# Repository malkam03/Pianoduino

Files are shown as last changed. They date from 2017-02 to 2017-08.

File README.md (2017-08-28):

# Pianoduino
A 61 key MIDI keyboard project with Arduino and some parts of a broken Yamaha PSR-E303. With control knobs, buttons, LCD and resistive panel. 
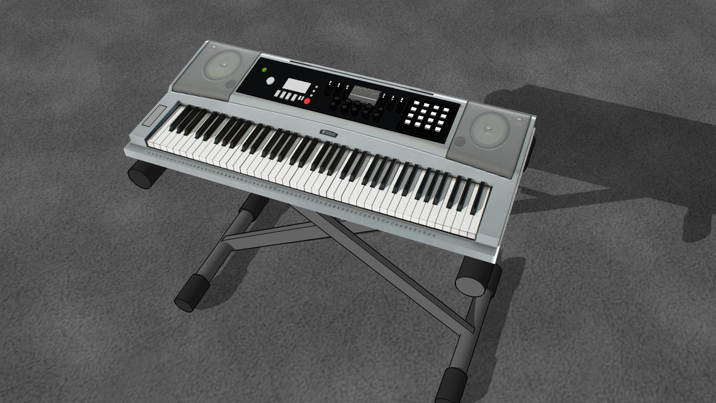
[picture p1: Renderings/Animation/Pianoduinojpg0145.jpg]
Image of Pianoduino

## Getting Started
Since this is a hardware and software project, these instructions will get you a copy of the project up and running on your device for development and testing purposes.  

### Prerequisites

**Arduino Circuit**
First you need to build the [circuit](PCB/Pianoduino/Mainboard.brd) if you have a Yamaha PSR-E303, or you can modify it to fit your keys circuit.
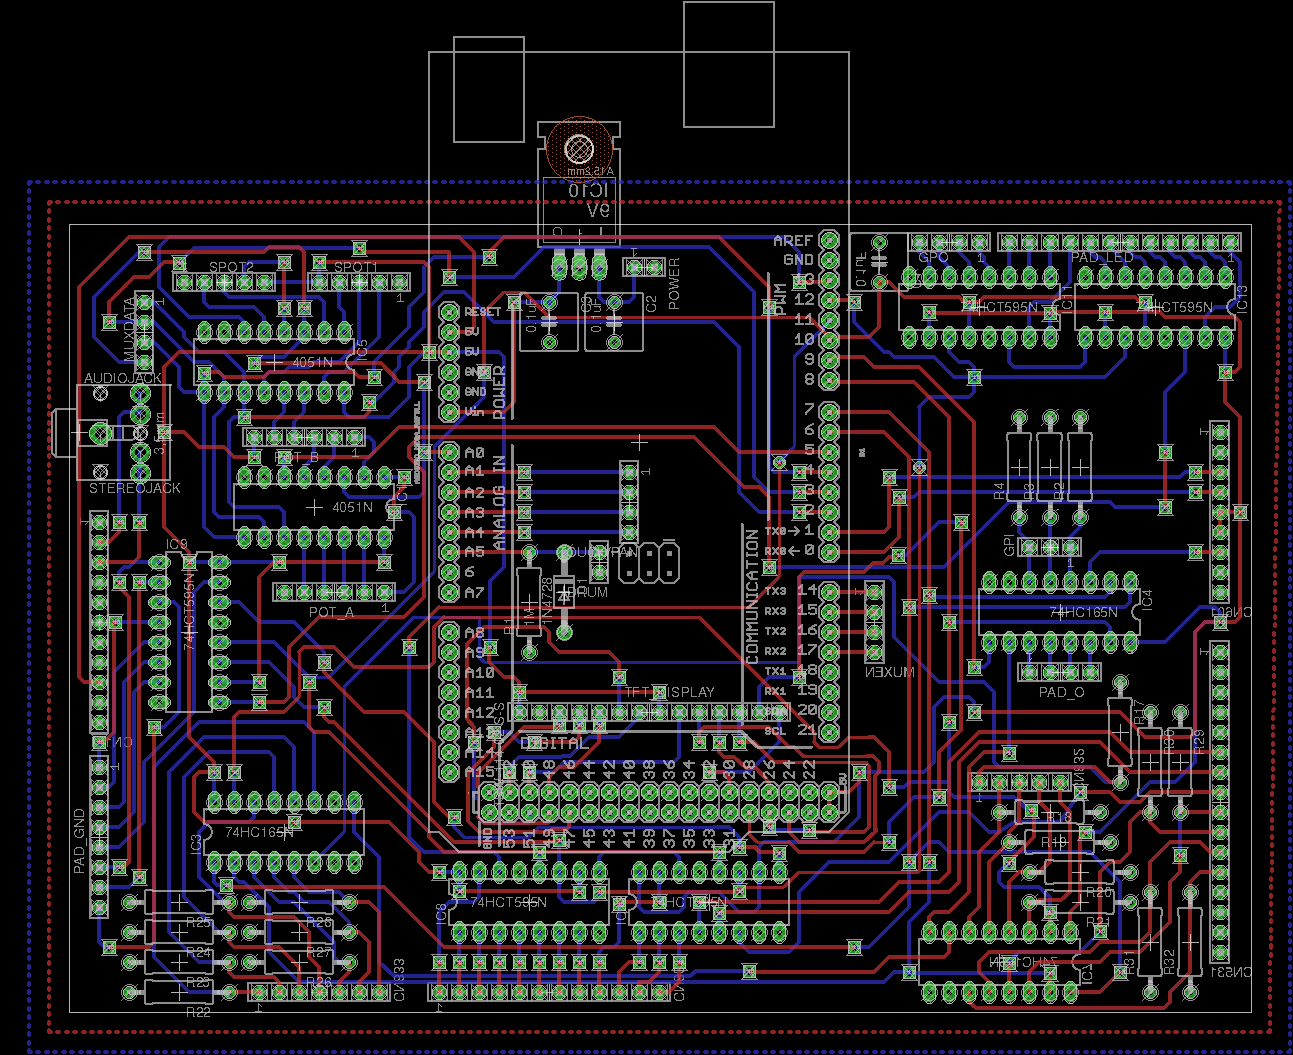
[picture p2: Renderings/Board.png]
PCB


**Arduino IDE** to edit and upload your code.
You can find the instructions of installation on the Arduino's [page](https://www.arduino.cc/en/Main/Software) depending on your operative system.

**Autodesk Eagle** to edit the circuit.
You can find the instructions of installation on the autodesk's [page](https://www.autodesk.com/products/eagle/free-download) depending on your operative system.

## Deployment

Just upload your code to the arduino + circuit and play :musical_keyboard:.

## Author
* **Malcolm Davis** - *Initial work* - [Pianoduino](https://github.com/malkam03/Pianoduino)

See also the list of [contributors](https://github.com/malkam03/Pianoduino/contributors.md) who participated in this project.

## License

This project is licensed under the MIT License - see the [LICENSE.md](LICENSE.md) file for details.

## Acknowledgments

* [Brian Benchoff](https://hackaday.com/2012/11/28/turning-toy-pianos-into-midi-keyboards/)
* [dylanstout](http://www.instructables.com/id/Arduino-MIDI-Controller/)
* [cgmalantonio](http://www.instructables.com/id/Touch-Screen-Overlay-with-Arduino/)

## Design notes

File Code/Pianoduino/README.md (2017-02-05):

# Pianoduino
A 61 key MIDI keyboard project with Arduino. With control knobs, buttons, LCD and resistive panel.

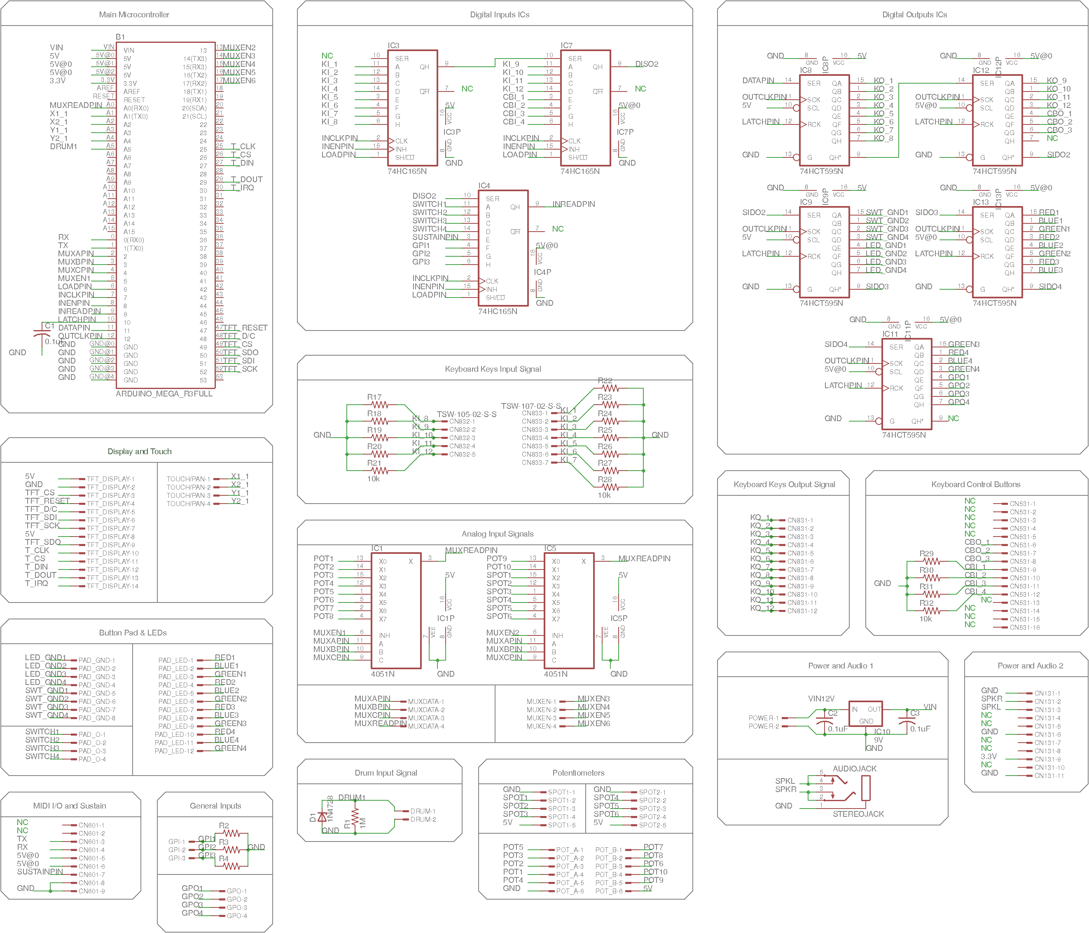
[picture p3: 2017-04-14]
Renderings/Schematic.png

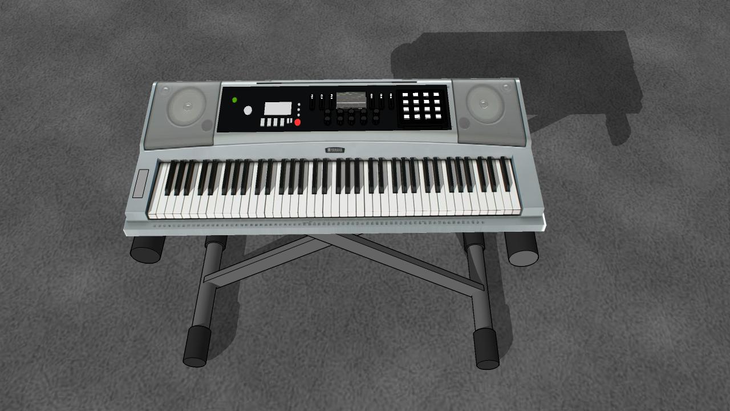
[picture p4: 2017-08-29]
Renderings/Animation/Pianoduinojpg0058.jpg

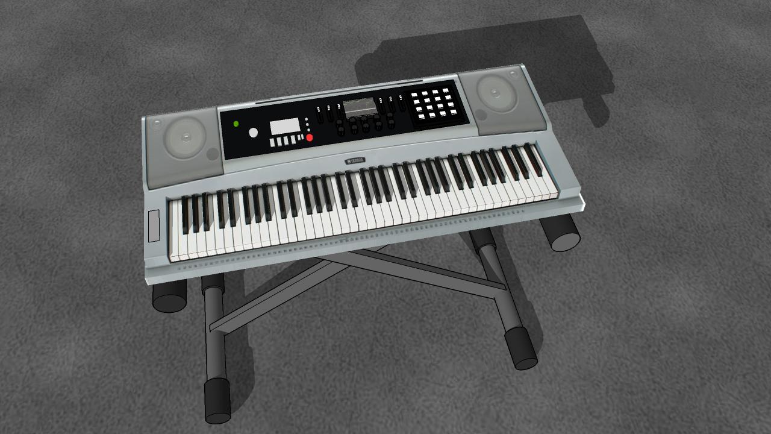
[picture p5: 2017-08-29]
Renderings/Animation/Pianoduinojpg0084.jpg

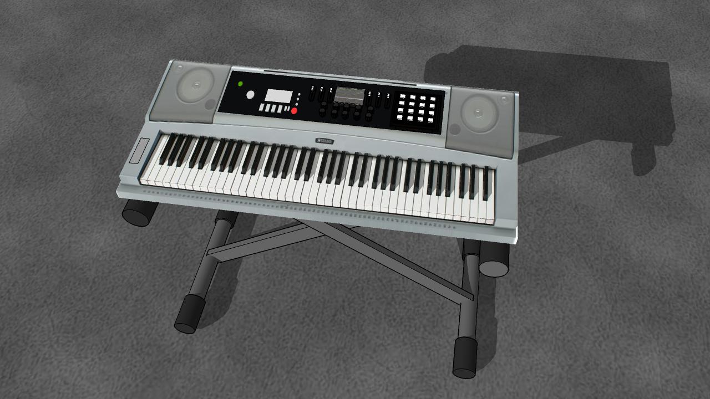
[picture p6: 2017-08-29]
Renderings/Animation/Pianoduinojpg0034.jpg

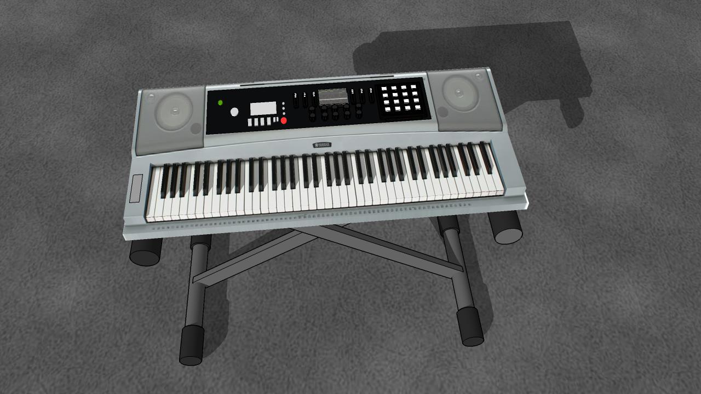
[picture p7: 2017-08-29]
Renderings/Animation/Pianoduinojpg0069.jpg

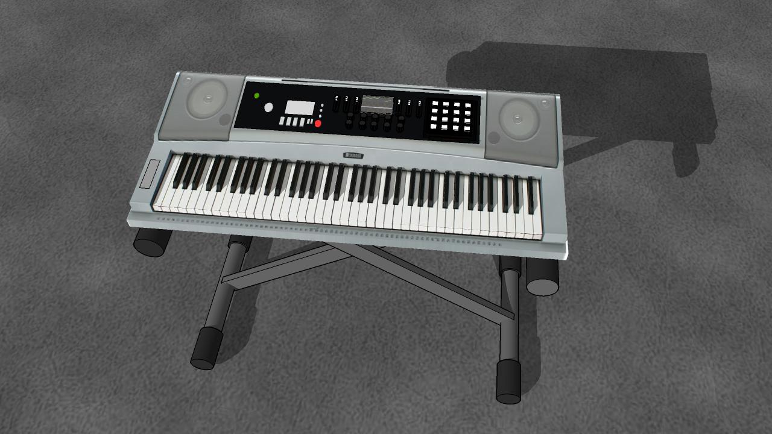
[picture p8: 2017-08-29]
Renderings/Animation/Pianoduinojpg0042.jpg

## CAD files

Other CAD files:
Datasheets/TJCTM32024_SPI/51_Code-keil/»ù±¾Ë¢ÆÁ²âÊÔ/main.OBJ
Datasheets/TJCTM32024_SPI/51_Code-keil/×ÛºÏ²âÊÔ(ÒªÇó´óÓÚ16K ROMµÄµ¥Æ¬»ú)/×ÛºÏ²âÊÔ(ÒªÇó´óÓÚ16K ROMµÄµ¥Æ¬»ú)/main.OBJ
Datasheets/TJCTM32024_SPI/51_Code-keil/»ù±¾Ë¢ÆÁ²âÊÔ/sys.obj
Datasheets/TJCTM32024_SPI/51_Code-keil/×ÛºÏ²âÊÔ(ÒªÇó´óÓÚ16K ROMµÄµ¥Æ¬»ú)/×ÛºÏ²âÊÔ(ÒªÇó´óÓÚ16K ROMµÄµ¥Æ¬»ú)/touch.obj
Datasheets/TJCTM32024_SPI/51_Code-keil/»ù±¾Ë¢ÆÁ²âÊÔ/LCD.obj
Datasheets/TJCTM32024_SPI/51_Code-keil/×ÛºÏ²âÊÔ(ÒªÇó´óÓÚ16K ROMµÄµ¥Æ¬»ú)/×ÛºÏ²âÊÔ(ÒªÇó´óÓÚ16K ROMµÄµ¥Æ¬»ú)/STARTUP.OBJ
Datasheets/TJCTM32024_SPI/51_Code-keil/»ù±¾Ë¢ÆÁ²âÊÔ/font.obj
Datasheets/TJCTM32024_SPI/51_Code-keil/×ÛºÏ²âÊÔ(ÒªÇó´óÓÚ16K ROMµÄµ¥Æ¬»ú)/×ÛºÏ²âÊÔ(ÒªÇó´óÓÚ16K ROMµÄµ¥Æ¬»ú)/sys.obj
Datasheets/TJCTM32024_SPI/51_Code-keil/»ù±¾Ë¢ÆÁ²âÊÔ/touch.obj
Datasheets/TJCTM32024_SPI/51_Code-keil/×ÛºÏ²âÊÔ(ÒªÇó´óÓÚ16K ROMµÄµ¥Æ¬»ú)/×ÛºÏ²âÊÔ(ÒªÇó´óÓÚ16K ROMµÄµ¥Æ¬»ú)/font.obj
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

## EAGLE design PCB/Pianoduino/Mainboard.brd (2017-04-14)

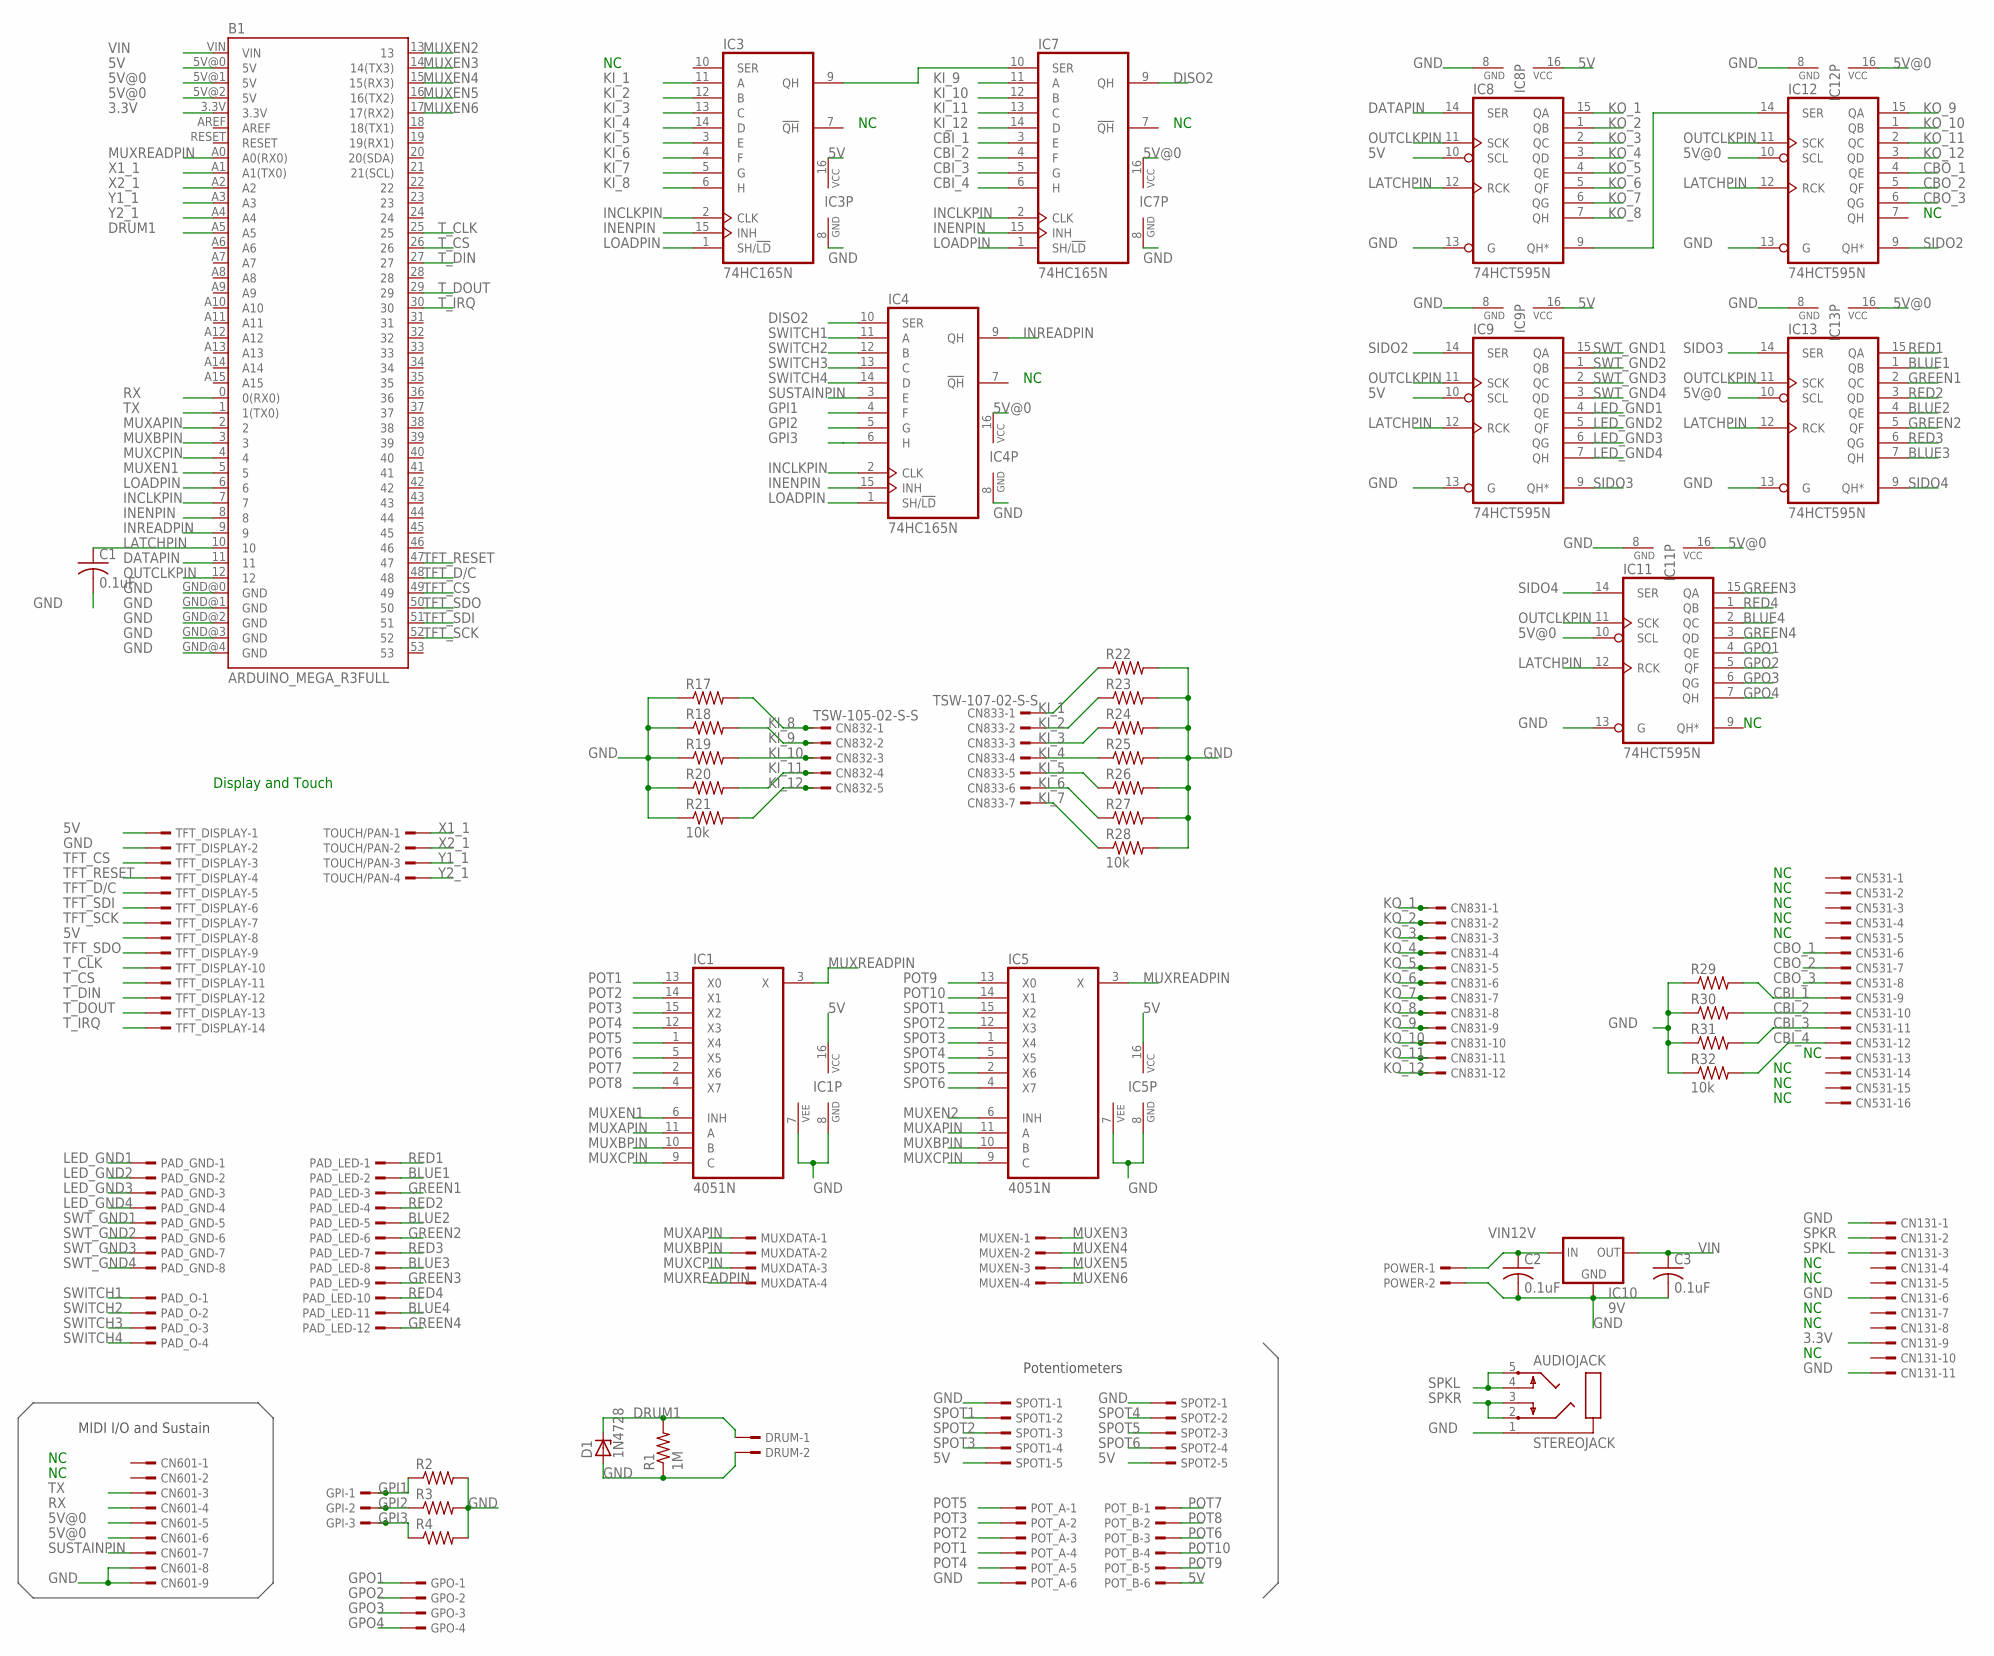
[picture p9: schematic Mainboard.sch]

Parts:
AUDIOJACK: STEREOJACK; STX3100
B1: ARDUINO_MEGA_R3FULL; ARDUINO_MEGA
C1, C2, C3: 0.1uF; C050-075X075
CN131: TSW-111-02-S-S
CN531: TSW-116-02-S-S
CN601: TSW-109-02-S-S
CN831: TSW-112-02-S-S
CN832: TSW-105-02-S-S
CN833: TSW-107-02-S-S
D1: 1N4728; DO41Z10
DRUM: TSW-102-02-S-S
GPI: TSW-103-02-S-S
GPO: TSW-104-02-S-S
IC1, IC5: 4051N; DIL16
IC3, IC4, IC7: 74HC165N; DIL16
IC8, IC9, IC11, IC12, IC13: 74HCT595N; DIL16
IC10: 9V; 78XXL
MUXDATA: TSW-104-02-S-S
MUXEN: TSW-104-02-S-S
PAD_GND: TSW-108-02-S-S
PAD_LED: TSW-112-02-S-S
PAD_O: TSW-104-02-S-S
POT_A: TSW-106-02-S-S
POT_B: TSW-106-02-S-S
POWER: TSW-102-02-S-S
R1: 1M; 0309/12
R2, R3, R4, R17, R18, R19, R20, R21, R22, R23, R24, R25, R26, R27, R28, R29, R30, R31, R32: 10k; 0309/12
SPOT1, SPOT2: TSW-105-02-S-S
TFT_DISPLAY: TSW-114-02-S-S
TOUCH/PAN: TSW-104-02-S-S

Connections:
3.3V: B1.3.3V, CN131.9
5V: B1.5V@0 (5V), IC1.16 (VCC), IC3.16 (VCC), IC5.16 (VCC), IC8.10 (SCL), IC8.16 (VCC), IC9.10 (SCL), IC9.16 (VCC), POT_B.6, SPOT1.5, SPOT2.5, TFT_DISPLAY.1, TFT_DISPLAY.8
5V@0: B1.5V@1 (5V), B1.5V@2 (5V), CN601.5, CN601.6, IC4.16 (VCC), IC7.16 (VCC), IC11.10 (SCL), IC11.16 (VCC), IC12.10 (SCL), IC12.16 (VCC), IC13.10 (SCL), IC13.16 (VCC)
BLUE1: IC13.1 (QB), PAD_LED.2
BLUE2: IC13.4 (QE), PAD_LED.5
BLUE3: IC13.7 (QH), PAD_LED.8
BLUE4: IC11.2 (QC), PAD_LED.11
CBI_1: CN531.9, IC7.3 (E), R29.2
CBI_2: CN531.10, IC7.4 (F), R30.2
CBI_3: CN531.11, IC7.5 (G), R31.2
CBI_4: CN531.12, IC7.6 (H), R32.2
CBO_1: CN531.6, IC12.4 (QE)
CBO_2: CN531.7, IC12.5 (QF)
CBO_3: CN531.8, IC12.6 (QG)
DATAPIN: B1.11, IC8.14 (SER)
DISO1: IC3.9 (QH), IC7.10 (SER)
DISO2: IC4.10 (SER), IC7.9 (QH)
DRUM1: B1.A5, D1.C, DRUM.1, R1.2
GND: AUDIOJACK.1, B1.GND@0 (GND), B1.GND@1 (GND), B1.GND@2 (GND), B1.GND@3 (GND), B1.GND@4 (GND), C1.2, C2.2, C3.2, CN131.1, CN131.6, CN131.11, CN601.8, CN601.9, D1.A, DRUM.2, IC1.7 (VEE), IC1.8 (GND), IC3.8 (GND), IC4.8 (GND), IC5.7 (VEE), IC5.8 (GND), IC7.8 (GND), IC8.8 (GND), IC8.13 (G), IC9.8 (GND), IC9.13 (G), IC10.GND, IC11.8 (GND), IC11.13 (G), IC12.8 (GND), IC12.13 (G), IC13.8 (GND), IC13.13 (G), POT_A.6, POWER.2, R1.1, R2.2, R3.2, R4.2, R17.1, R18.1, R19.1, R20.1, R21.1, R22.2, R23.2, R24.2, R25.2, R26.2, R27.2, R28.2, R29.1, R30.1, R31.1, R32.1, SPOT1.1, SPOT2.1, TFT_DISPLAY.2
GPI1: GPI.1, IC4.4 (F), R2.1
GPI2: GPI.2, IC4.5 (G), R3.1
GPI3: GPI.3, IC4.6 (H), R4.1
GPO1: GPO.1, IC11.4 (QE)
GPO2: GPO.2, IC11.5 (QF)
GPO3: GPO.3, IC11.6 (QG)
GPO4: GPO.4, IC11.7 (QH)
GREEN1: IC13.2 (QC), PAD_LED.3
GREEN2: IC13.5 (QF), PAD_LED.6
GREEN3: IC11.15 (QA), PAD_LED.9
GREEN4: IC11.3 (QD), PAD_LED.12
INCLKPIN: B1.7, IC3.2 (CLK), IC4.2 (CLK), IC7.2 (CLK)
INENPIN: B1.8, IC3.15 (INH), IC4.15 (INH), IC7.15 (INH)
INREADPIN: B1.9, IC4.9 (QH)
KI_1: CN833.1, IC3.11 (A), R22.1
KI_2: CN833.2, IC3.12 (B), R23.1
KI_3: CN833.3, IC3.13 (C), R24.1
KI_4: CN833.4, IC3.14 (D), R25.1
KI_5: CN833.5, IC3.3 (E), R26.1
KI_6: CN833.6, IC3.4 (F), R27.1
KI_7: CN833.7, IC3.5 (G), R28.1
KI_8: CN832.1, IC3.6 (H), R17.2
KI_9: CN832.2, IC7.11 (A), R18.2
KI_10: CN832.3, IC7.12 (B), R19.2
KI_11: CN832.4, IC7.13 (C), R20.2
KI_12: CN832.5, IC7.14 (D), R21.2
KO_1: CN831.1, IC8.15 (QA)
KO_2: CN831.2, IC8.1 (QB)
KO_3: CN831.3, IC8.2 (QC)
KO_4: CN831.4, IC8.3 (QD)
KO_5: CN831.5, IC8.4 (QE)
KO_6: CN831.6, IC8.5 (QF)
KO_7: CN831.7, IC8.6 (QG)
KO_8: CN831.8, IC8.7 (QH)
KO_9: CN831.9, IC12.15 (QA)
KO_10: CN831.10, IC12.1 (QB)
KO_11: CN831.11, IC12.2 (QC)
KO_12: CN831.12, IC12.3 (QD)
LATCHPIN: B1.10, C1.1, IC8.12 (RCK), IC9.12 (RCK), IC11.12 (RCK), IC12.12 (RCK), IC13.12 (RCK)
LED_GND1: IC9.4 (QE), PAD_GND.1
LED_GND2: IC9.5 (QF), PAD_GND.2
LED_GND3: IC9.6 (QG), PAD_GND.3
LED_GND4: IC9.7 (QH), PAD_GND.4
LOADPIN: B1.6, IC3.1 (SH/!LD), IC4.1 (SH/!LD), IC7.1 (SH/!LD)
MUXAPIN: B1.2, IC1.11 (A), IC5.11 (A), MUXDATA.1
MUXBPIN: B1.3, IC1.10 (B), IC5.10 (B), MUXDATA.2
MUXCPIN: B1.4, IC1.9 (C), IC5.9 (C), MUXDATA.3
MUXEN1: B1.5, IC1.6 (INH)
MUXEN2: B1.13, IC5.6 (INH)
MUXEN3: B1.14 (14(TX3)), MUXEN.1
MUXEN4: B1.15 (15(RX3)), MUXEN.2
MUXEN5: B1.16 (16(TX2)), MUXEN.3
MUXEN6: B1.17 (17(RX2)), MUXEN.4
MUXREADPIN: B1.A0 (A0(RX0)), IC1.3 (X), IC5.3 (X), MUXDATA.4
unnamed: IC8.9 (QH*), IC12.14 (SER)
OUTCLKPIN: B1.12, IC8.11 (SCK), IC9.11 (SCK), IC11.11 (SCK), IC12.11 (SCK), IC13.11 (SCK)
POT1: IC1.13 (X0), POT_A.4
POT2: IC1.14 (X1), POT_A.3
POT3: IC1.15 (X2), POT_A.2
POT4: IC1.12 (X3), POT_A.5
POT5: IC1.1 (X4), POT_A.1
POT6: IC1.5 (X5), POT_B.3
POT7: IC1.2 (X6), POT_B.1
POT8: IC1.4 (X7), POT_B.2
POT9: IC5.13 (X0), POT_B.5
POT10: IC5.14 (X1), POT_B.4
RED1: IC13.15 (QA), PAD_LED.1
RED2: IC13.3 (QD), PAD_LED.4
RED3: IC13.6 (QG), PAD_LED.7
RED4: IC11.1 (QB), PAD_LED.10
RX: B1.0 (0(RX0)), CN601.4
SIDO2: IC9.14 (SER), IC12.9 (QH*)
SIDO3: IC9.9 (QH*), IC13.14 (SER)
SIDO4: IC11.14 (SER), IC13.9 (QH*)
SPKL: AUDIOJACK.4, AUDIOJACK.5, CN131.3
SPKR: AUDIOJACK.2, AUDIOJACK.3, CN131.2
SPOT1: IC5.15 (X2), SPOT1.2
SPOT2: IC5.12 (X3), SPOT1.3
SPOT3: IC5.1 (X4), SPOT1.4
SPOT4: IC5.5 (X5), SPOT2.2
SPOT5: IC5.2 (X6), SPOT2.3
SPOT6: IC5.4 (X7), SPOT2.4
SUSTAINPIN: CN601.7, IC4.3 (E)
SWITCH1: IC4.11 (A), PAD_O.1
SWITCH2: IC4.12 (B), PAD_O.2
SWITCH3: IC4.13 (C), PAD_O.3
SWITCH4: IC4.14 (D), PAD_O.4
SWT_GND1: IC9.15 (QA), PAD_GND.5
SWT_GND2: IC9.1 (QB), PAD_GND.6
SWT_GND3: IC9.2 (QC), PAD_GND.7
SWT_GND4: IC9.3 (QD), PAD_GND.8
TFT_CS: B1.49, TFT_DISPLAY.3
TFT_D/C: B1.48, TFT_DISPLAY.5
TFT_RESET: B1.47, TFT_DISPLAY.4
TFT_SCK: B1.52, TFT_DISPLAY.7
TFT_SDI: B1.51, TFT_DISPLAY.6
TFT_SDO: B1.50, TFT_DISPLAY.9
TX: B1.1 (1(TX0)), CN601.3
T_CLK: B1.25, TFT_DISPLAY.10
T_CS: B1.26, TFT_DISPLAY.11
T_DIN: B1.27, TFT_DISPLAY.12
T_DOUT: B1.29, TFT_DISPLAY.13
T_IRQ: B1.30, TFT_DISPLAY.14
VIN: B1.VIN, C3.1, IC10.OUT
VIN12V: C2.1, IC10.IN, POWER.1
X1_1: B1.A1 (A1(TX0)), TOUCH/PAN.1
X2_1: B1.A2, TOUCH/PAN.2
Y1_1: B1.A3, TOUCH/PAN.3
Y2_1: B1.A4, TOUCH/PAN.4

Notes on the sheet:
MIDI I/O and Sustain
Potentiometers
Display and Touch

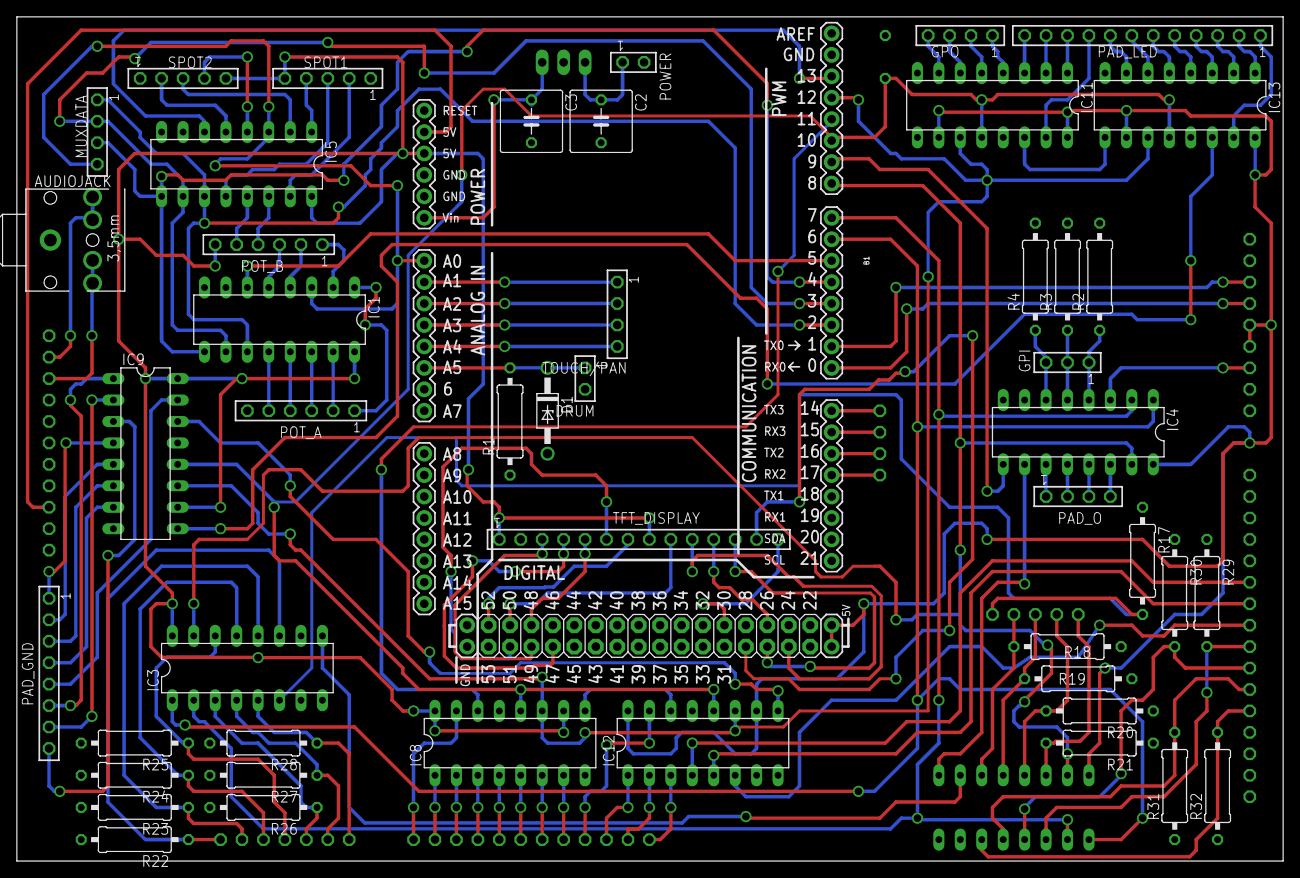
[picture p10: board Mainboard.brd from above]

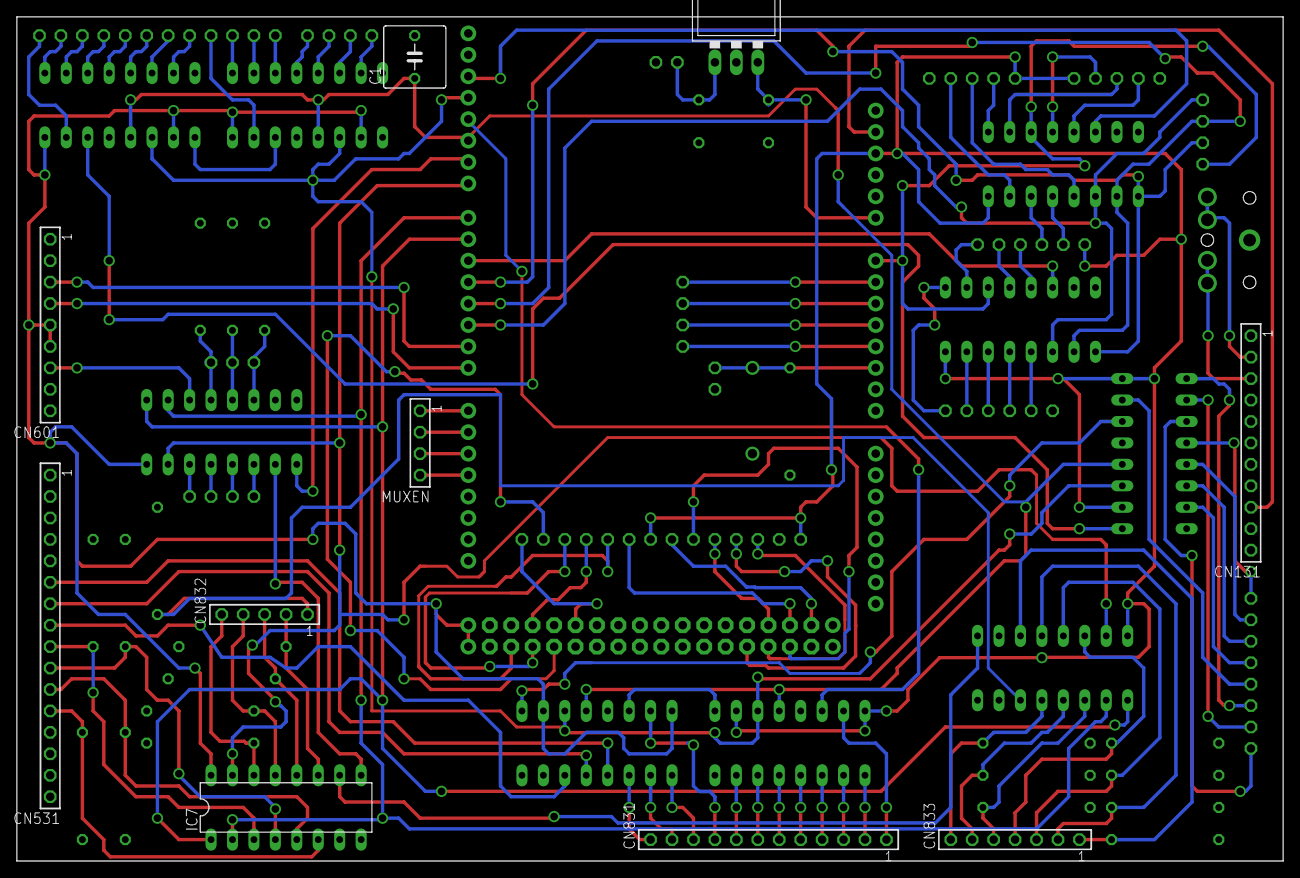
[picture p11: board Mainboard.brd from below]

Board: 2 copper layers, 150.0 x 100.0 mm, 58 parts (10 on the bottom side), 128 nets.

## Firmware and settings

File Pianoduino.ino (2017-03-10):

/**
 * <h1>Pianoduino</h1>
 * 61 key MIDI Keyboard with Arduino Uno Code, 24 shiftout outputs, 24 shiftin inputs
 * 1 resistive touchscreen and 16 analog I/O.
 * @author Malcolm Davis
 * @version 0.1
 * @since 2017-02-03
 */

//*********************Arduino Pins*************************//
static const byte muxAPin = 2;
static const byte muxBPin = 3;
static const byte muxCPin = 4;
static const byte muxReadPin = A0;
static const byte inClkPin = 7; //Shift in clock
static const byte loadPin = 6; //Shift in or load input. When high data, shifted. When Low data is loaded from parallel inputs.
static const byte inEnPin = 8; //Active low
static const byte inReadPin = 9;
static const byte dataPin = 11;
static const byte outClkPin = 12;
static const byte latchPin = 10;
//If a Analog mux is added, just connect the control pins in parallel and add the En pin to the list.
static const byte muxEn [] = {
  5};
//**********************************************************//

//**************************Constants*********************//
byte mask[] = { 
  B00000001, B00000010, B00000100, B00001000, B00010000, B00100000, B01000000, B10000000 };//To read the columns values
static const byte  keyMidiCons[144] = {
  0, 0, 0, 0, 0, 0, 0, 0, 0, 0, 0, 0,
  0, 0, 0, 0, 0, 0, 0, 0, 0, 0, 0, 0,
  0, 0, 0, 0, 0, 0, 0, 0, 0, 0, 0, 0,
  B00101000, B00101000, B00101001, B00101001, B00101010, B00101010, B00101011, B00101011, B00101100, B00101100, B00100111, B00100111,
  B00101110, B00101110, B00101111, B00101111, B00110000, B00110000, B00101011, B00101011, B00101100, B00101100, B00101101, B00101101,
  B00111010, B00111010, B00111011, B00111011, 0, 0, B00110111, B00110111, B00111000, B00111000, B00111001, B00111001,
  B00110100, B00110100, B00110101, B00110101, B00110110, B00110110, B00110001, B00110001, B00110010, B00110010, B00110011, B00110011,
  B01010010, B01010010, B01010011, B01010011, B01010100, B01010100, B01001111, B01001111, B01010000, B01010000, B01010001, B01010001,
  B01001100, B01001100, B01001101, B01001101, B01001110, B01001110, B01001001, B01001001, B01001010, B01001010, B01001011, B01001011,
  B01000110, B01000110, B01000111, B01000111, B01001000, B01001000, B01000011, B01000011, B01000100, B01000100, B01000101, B01000101,
  B01000000, B01000000, B01000001, B01000001, B01000010, B01000010, B00111101, B00111101, B00111110, B00111110, B00111111, B00111111,
  0, 0, 0, 0, B00111100, B00111100, 0, 0, 0, 0, 0, 0
};
static const byte drumNotes []= {
  B00100110
}; //Drums note, snaredrum,...
static const byte blank = B00000000;//To send blank to the register.
static const byte noteON = B10010000;
static const byte noteOFF = B10000000;
static const byte control = B10110000;
static const byte pitchBend = B11100000;
static const byte  padMidi = B00000000; //Pad first note.
static const byte  buttonMidi = B00010000; //Controll general first code.
static const byte analogMidi =B00110000; //Controll general first code.
// MIDI codes taken from http://nickfever.com/music/midi-cc-list
static const byte MIDI_CC_MODULATION = B00000001;
static const byte MIDI_CC_VOLUME = B00000111;
static const byte MIDI_CC_BALANCE = B00001000;
static const byte MIDI_CC_SUSTAIN = B00101000;
static const byte MIDI_CC_NOTES_OFF = B01111011;



//Shift in movements(3 shift registers and 8 pins per shift register)
//The sum of all the rows have to be smaller or equal to the shift in registers.
static const byte shiftIns=24; 
//*******************Configuration constants**********************//
//Don't change this values unless you change the hardware.
static const byte keyColumns = 12;
static const byte keyRows = 12; //
static const byte buttonColumns = 3;
static const byte buttonRows = 4; 
static const byte padColumns = 4;
static const byte padRows = 4;
//This values can be changed.
static const short sensitivity = 1000;
static const byte keyboardChannel = 1;
static const byte buttonPadChannel = 2;
static const byte controlChannel = 3;
static const byte drumsChannel = 4;
static const byte drumsThreshold [] = { 
40 
};//Drums threshold, snaredrum,...
static const byte analogThreshold = 1;
//#define debug //Uncomment to debug
//***************************************************************//

//*******************************Variables**********************//
static bool sValue[] = {
  0, 0, 0}; // S0, S1, S2 values
long noteTime [sizeof(keyMidiCons) / sizeof(byte) / 2]; //Time that the note have been pressed.
bool keyState[sizeof(keyMidiCons) / sizeof(byte)]; //State of the key.
bool buttonState[buttonColumns*buttonRows]; //State of the buttons.
bool padState[padRows*padColumns]; //State of the pad buttons.
bool rowsRead [keyRows+buttonRows]; // Rows shift in values.
byte trans = 0; //Level to transpose the octaves.
static byte  keyMidi[sizeof(keyMidiCons) / sizeof(byte)]; 
byte analogValue[(sizeof(muxEn) / sizeof(byte)) * 8]; 
//**************************************************************//


/**
 * Method to setup the pins and stuffs of the pianoduino.
 * @param none
 * @return void
 */
void setup() {
  byte i;
  Serial.begin(115200);
#ifdef debug 
  Serial.println("Setup Start");
#endif
  pinMode(muxAPin, OUTPUT);
  pinMode(muxBPin, OUTPUT);
  pinMode(muxCPin, OUTPUT);
  pinMode(inClkPin, OUTPUT);
  pinMode(loadPin, OUTPUT);
  pinMode(inEnPin, OUTPUT);
  pinMode(inReadPin, INPUT);
  pinMode(dataPin, OUTPUT);
  pinMode(latchPin, OUTPUT);
  pinMode(outClkPin, OUTPUT);
  //Set the enabler pins to outputs.
  for (i = 0; i < sizeof(muxEn) / sizeof(int); i++) {
    pinMode(muxEn[i], OUTPUT);
  }
  //Set the note times to 0
  for (i = 0; i < sizeof(noteTime) / sizeof(long); i++) {
    noteTime[i] = 0;
  }
  //Set all the notes as off
  for (i = 0; i < sizeof(keyState) / sizeof(bool); i++) {
    keyState[i] = 0;
  }
  //Set all the row read values to false
  for (i = 0; i < keyRows+buttonRows; i++){
    rowsRead[i] = false;
  }
  //Set all the buttons of the pad to off.
  for (i = 0; i < padColumns*padRows; i++){
    padState[i] = 0;
  }
  //Set all the buttons of the pad to off.
  for (i = 0; i < buttonRows*buttonColumns; i++){
    buttonState[i] = 0;
  }

  readAnalog(); //Read the initial value of the knobs
  transpose(trans); //Set the octave to the initial value.
  digitalWrite(loadPin, HIGH); //On HIGH is read ready
  delay(1000); //Waits a second.
#ifdef debug 
  Serial.println("Setup Ready");
#endif
}

/**
 * Method to select a pin of a mux
 * @param pPin: the mux pin that you want to write or read.
 * @param pMuxEn: the pin of the mux that you want to read from.
 * @return void
 */
void muxToPin(byte pPin, byte pMuxEn) {
  sValue[0] = bitRead(pPin, 0);
  sValue[1] = bitRead(pPin, 1);
  sValue[2] = bitRead(pPin, 2);
  for (byte i = 0; i < sizeof(muxEn) / sizeof(byte); i++) {
    if (pMuxEn != i) {
      digitalWrite(muxEn[i], HIGH);
    }
  }
  digitalWrite(pMuxEn, LOW);
  digitalWrite(muxAPin, sValue[0]);
  digitalWrite(muxBPin, sValue[1]);
  digitalWrite(muxCPin, sValue[2]);
}

/**
 * Method to shift the registers to a matrix column
 * @param pColumn the column you wish to shift to.
 * @return void
 */
void shiftToColumn(byte pColumn) {
#ifdef debug 
  Serial.print("Shifting to column: ");
  Serial.println(pColumn);
  delay(10);
#endif
  digitalWrite(latchPin, LOW);
  if (pColumn < 8) {
    shiftOut(dataPin, outClkPin, MSBFIRST, mask[pColumn]);
    shiftOut(dataPin, outClkPin, MSBFIRST, blank);
    shiftOut(dataPin, outClkPin, MSBFIRST, mask[pColumn]);
  } 
  else {
    shiftOut(dataPin, outClkPin, MSBFIRST, mask[pColumn % 8]);
    shiftOut(dataPin, outClkPin, MSBFIRST, mask[pColumn % 8]);
    shiftOut(dataPin, outClkPin, MSBFIRST, blank);
  }
  digitalWrite(latchPin, HIGH);
#ifdef debug 
  Serial.println("Shift done.");
#endif
  delayMicroseconds(5);
}

/**
 * Method to transpose the notes
 * @param pDir direction to transpose
 */
void transpose(byte pDir) {
  if (-3 < trans + pDir ) {
    if (trans + pDir < 5) {
      trans = trans + pDir;
    } 
    else {
      trans = 4;
    }
  } 
  else {
    trans = -2;
  }
  for (byte i = 0; i <  sizeof(keyMidi) / sizeof(byte); i++) {
    keyMidi[i] = keyMidiCons[i] + trans * 12;
  }
}

/**
 * Method to read all the values of the knobs and other analog components. (Like the snaredrum.
 * Updates the analogValue array.
 */
void readAnalog() {
#ifdef debug 
  Serial.println("readAnalog start");
#endif
  byte tmp = 0;
  for (byte i = 0; i < sizeof(muxEn) / sizeof(byte); i++) {
    for (byte y = 0; y < 8; y++) {
      muxToPin(y, muxEn[i]);
      tmp = map(analogRead(muxReadPin), 0, 1023, 0, 127);
      if (i * 8 + y < 15) {
        //If the value is greater or smaller than the actual value plus or minus the threshold send the change value.
        if (tmp > analogValue[i * 8 + y] + analogThreshold || tmp < analogValue[i * 8 + y] - analogThreshold  ) {

          analogValue[i * 8 + y] = tmp;
          //Send message with the knoobs value
          controlMessage(controlChannel, i * 8 + y, tmp);
        }
      }
      else if(tmp > drumsThreshold[(i * 8 + y)%15]){
        //Send message with the drums value
        noteOn(drumsChannel, drumNotes[(i * 8 + y)%15], tmp);
      }
    }
  }
#ifdef debug 
  Serial.println("readAnalog pass");
#endif
}

/**
 * Method to read all the values of the keys and send the notes through MIDI.
 */
void readKeys(){
  for (byte i = 0; i < keyColumns; i++) {
    shiftToColumn(i);
    scanRows();
    for (byte j = 0; j < keyRows; j++) {
      if (rowsRead[j] && !keyState[i + keyColumns * j]) {
        keyState[i + keyColumns * j] = 1;
        if ((i + keyColumns * j) % 2 == 0) {
          if (keyState[i + keyColumns * j + 1] == 1) {
            noteOn(keyboardChannel, keyMidi[i + keyColumns * j], getVelocity((i + keyColumns * j) / 2));
          } 
          else {
            updateVelocity((i + keyColumns * j) / 2, (byte)1);
          }
        } 
        else {
          if (keyState[i + 12 * j - 1] == 1) {
            noteOn(keyboardChannel, keyMidi[i + keyColumns * j], getVelocity((i + keyColumns * j) / 2));
          }
          else {
            updateVelocity((i + keyColumns * j) / 2, (byte)1);
          }
        }
#ifdef debug
        Serial.print("Column ");
        Serial.println(i);
        Serial.print("Row ");
        Serial.println(j);
#endif
      } 
      else {
        if (keyState[i + keyColumns * j] && !rowsRead[j]) {
          keyState[i + 12 * j] = 0;
          if ((i + 12 * j) % 2 == 0) {
            if (keyState[i + 12 * j + 1] == 0) {
              updateVelocity((i + 12 * j) / 2, (byte)0);
              noteOff(keyboardChannel, keyMidi[i + 12 * j]);
            }
          } 
          else {
            if (keyState[i + 12 * j - 1] == 0) {
              updateVelocity((i + 12 * j) / 2, (byte)0);
              noteOff(keyboardChannel, keyMidi[i + 12 * j]);
            }
          }
        }
      }
    }
  }
}

/**
 * Method to read all the values of the buttons and send the notes through MIDI.
 */
void readButtons(){
  byte buttonIndex = 0;
  for (byte i = keyColumns; i < buttonColumns+keyColumns; i++) {//Is done like this for the shift register index.
    shiftToColumn(i);
    scanRows();
    for (byte j = keyRows; j < keyRows+buttonRows; j++) {//Is done like this for the shift register index
      if (rowsRead[j] && !buttonState[buttonIndex]) {
        buttonState[buttonIndex] = 1;
        controlMessage(controlChannel, buttonMidi + buttonIndex, 127); 
#ifdef debug
        Serial.print("Column ");
        Serial.println(i);
        Serial.print("Row ");
        Serial.println(j);
#endif
      } 
      else {
        if (buttonState[buttonIndex] && !rowsRead[j]) {
          buttonState[buttonIndex] = 0;
        }
      }
      buttonIndex++;
    }
  }
}

/**
 * Method to update the velocity of a note
 * @param pPos the position of the note in the array.
 * @param pMode 0 to turn off the note, 1 to update.
 */
void updateVelocity(byte pPos, byte pMode) {
  if (pMode == 0) {
    noteTime[pPos] = 0;
  } 
  else {
    getVelocity(pPos);
  }
}

/**
 * Method that  updates the velocity of a note.
 * @param pPos the position of the note in the array.
 */
byte getVelocity(byte pPos) {
  if (noteTime[pPos] == 0) {
    noteTime[pPos] = millis();
    return 127;
  } 
  else {
    byte tempVelocity = map(abs(millis() - noteTime[pPos]), 0, sensitivity, 127, 10);
    noteTime[pPos] = millis();
    if (tempVelocity < 10) {
      tempVelocity = 10;
    }
    else {
      if (tempVelocity > 127) {
        tempVelocity = 127;
      }
    }
    return tempVelocity;
  }
}

/**
 * Method to scan the values of all the inputs of the shiftregisters
 */
void scanRows() {
#ifdef debug 
  Serial.println("Scanning rows start");
  Serial.print("Load pin: ");
  Serial.println(loadPin);
  Serial.print("inEnPin pin: ");
  Serial.println(inEnPin);
  Serial.print("inReadPin pin: ");
  Serial.println(inReadPin);
  delay(10);
#endif
  digitalWrite(loadPin, LOW); //On Low the parallel data is collected
  delayMicroseconds(5);
  digitalWrite(loadPin, HIGH); //On HIGH is read ready
  delayMicroseconds(5);
  digitalWrite(inEnPin, LOW); //Active Low
  shiftIn(inReadPin, inClkPin);
  digitalWrite(inEnPin, HIGH); //Active Low
#ifdef debug 
  Serial.println("Scanning rows end");
  delay(1);
#endif
}

/**
 * Shift in modification method to read varius shift registers.
 * @param pDatapin the pin to read.
 * @param pClk the shift registers clock pin.
 */
void shiftIn(byte pDatapin, byte pClk) {
#ifdef debug 
  Serial.println("ShiftIn Start");
  delay(1);
#endif
  for (short i = shiftIns - 1; i >= 0 ; i--)
  {
    digitalWrite(inClkPin, LOW);
    delayMicroseconds(5);
    rowsRead[i] = digitalRead(inReadPin);
    digitalWrite(inClkPin, HIGH);
  }
#ifdef debug
  Serial.println("ShiftIn End");
  delay(10);
#endif
}

/**
 * Method to send a control message with analog values.
 * @param pChannel the channel to send the message.
 * @param pControl the note to turn on.
 * @param pValue the value to send.
 */
void controlMessage(byte pChannel, byte pControl, byte pValue){
  pChannel += control-1;
  midiSend(pChannel,pControl, pValue);
}

/**
 * Method to send a note on message.  
 * @param pChannel the channel to send the noteon.
 * @param pPitch the note to turn on.
 * @param pVelocity the velocity of the note.
 */
void noteOn(byte pChannel, byte pPitch, byte pVelocity){
  pChannel += noteON-1;
  midiSend(pChannel, pPitch, pVelocity);
}

/**
 * Method to send a note off message.
 * @param pChannel the channel to send the noteoff.
 * @param pPitch the note to turn off.
 */
void noteOff(byte pChannel, byte pPitch){
  pChannel += noteOFF-1;
  midiSend(pChannel, pPitch, 0);
}

/**
 * Method to send the midi message.
 * @param statusByte the status midi command.
 * @param dataByte1 the first data byte.
 * @param dataByte2 the second data byte.
 * @return void
 */
void midiSend(byte statusByte, byte dataByte1, byte dataByte2) {
#ifdef debug
  Serial.println("Begin Message.");
  Serial.println(statusByte, BIN);
  Serial.println(dataByte1, BIN);
  Serial.println(dataByte2, BIN);
  Serial.println("End Message.");
#else
  Serial.write(statusByte);
  Serial.write(dataByte1);
  Serial.write(dataByte2);
#endif
}

/**
 * Main loop method
 * @param none
 * @return void
 */
void loop() {
#ifdef debug
  Serial.println("Loop start");
#endif
  readAnalog();
  readKeys();
  readButtons();
#ifdef debug
  Serial.println("Loop pass");
#endif
}

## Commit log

2017-02-06 First working version of the arduino code.
2017-02-12 Ghost notes that triggers inbetween the two switches, and velocity sensitivity added. Also the F# and G notes codes where added, so as a debug flag for some tests.
2017-02-21 Octave transposition method implemented, analog mux read methods added, to read the knobs values and the drums. Some ints where replaced by bytes to save space. Debug prints added to test some errors.
    [Pianoduino.ino]
2017-03-10 Added readAnalog, readButtons, readKey and other aux methods to implemment the knobs and buttons functions. Also some control variables and constants were added. The debug code has been modified.
2017-04-14 Schematic and pcb designd added, 3D model added.
    [Button_Pad_Breakout-v05.brd, Button_Pad_Breakout-v05.sch, LCD.obj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]
2017-05-28 Compile error fixed, fine tuning analogReads.
    [Pianoduino.ino]
2017-08-29 Stand added and some carpet too.
    [Sketch.skp]
2017-08-29 Ableton presets added.
    [Project8_1.cfg]

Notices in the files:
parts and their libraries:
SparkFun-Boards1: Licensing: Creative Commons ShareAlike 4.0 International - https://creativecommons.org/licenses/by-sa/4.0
